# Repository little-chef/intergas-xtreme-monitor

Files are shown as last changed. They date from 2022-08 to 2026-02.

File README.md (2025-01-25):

# Home-Assistant Intergas Central Heating monitor/controller

This project provides the necessary tools and scripts to monitor/control a Intergas
central heating system via the IDS diagnosis interface.

It connects an ESP32 NodeMCU board through optocouplers to the burner control
board of the Intergas Xtreme. From there detailed statistics are published to
Home Assistant for accurate monitoring/controlling of the device.

This project has only been qualified with a Intergas Xtreme 36 central heater.

## Features:

This project allows deep monitoring/controlling of all internal metrics/settings of the Intergas Xtreme.
(Screenshots below only show a subset of he possible settings, full list can be found [here](./esphome/intergas-xtreme-monitor.yaml#L83))

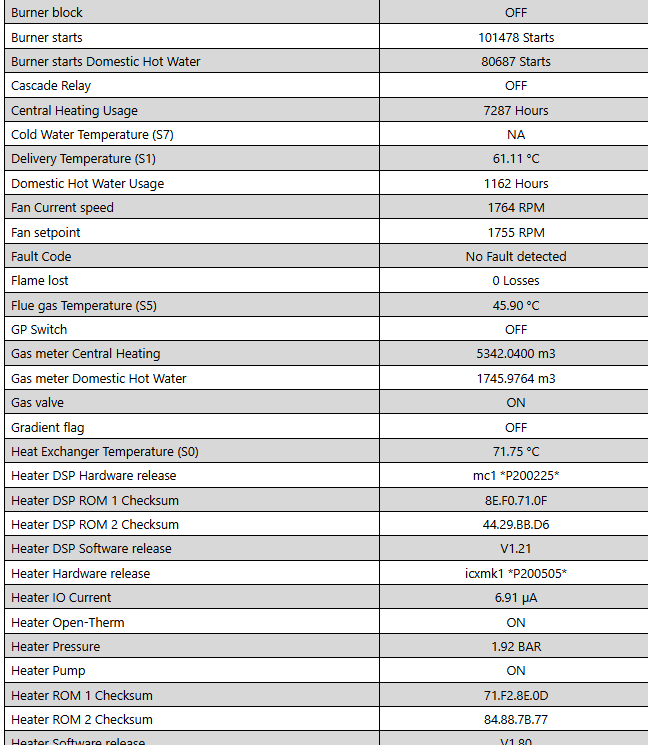
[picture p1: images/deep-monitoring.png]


It also aenables control of all configuration settings of the Intergas Xtreme via Home-Assistant,
including all 'Expert Settings'. This enables keeping track of these settings over time, and easy revert back
to older settings.
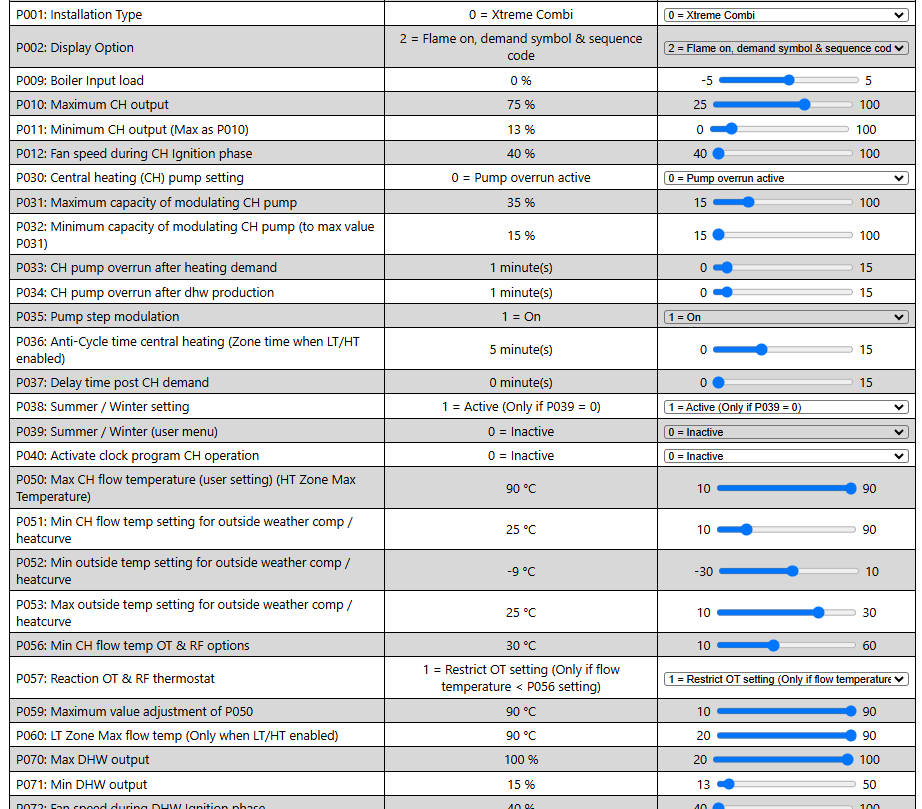
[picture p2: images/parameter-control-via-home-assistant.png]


# Home Assistant
The connection to Home Assistant is done via ESPHome and Wifi.

# Physical connection

Prerequisites for the physical connection:
* Cable required that connect to the X14 connector of the burner control board.
  The type of connector is a Molex Mini-Fit, Jr. connector housing with female
  terminals.

  For reference, the connector is:
  * [Molex part number 39-01-2200](https://www.conrad.nl/p/molex-39012040-mini-fit-jr-receptacle-housing-dual-row-4-circuits-ul-94v-2-natural-2448286), and
  * [the terminals are Molex part number 5556](https://www.conrad.nl/p/molex-39000078-100-pcs-mini-fit-female-crimp-terminal-tin-sn-over-copper-cu-plated-brass-16-awg-bag-2448254).

  This is also the same type of connector you can find on old ATX Power Supplies.

* As opto coupler we use the [4N25](https://www.conrad.nl/p/lite-on-optocoupler-fototransistor-4n25-dip-6-transistor-dc-1127375) type.

* As controller we use:
  * a [NodeMCU-32s (ESP32)](https://docs.platformio.org/en/latest/boards/espressif32/nodemcu-32s.html) Development board

# Schematics design

Schematics of the IDS adapter is designed with KiCad.
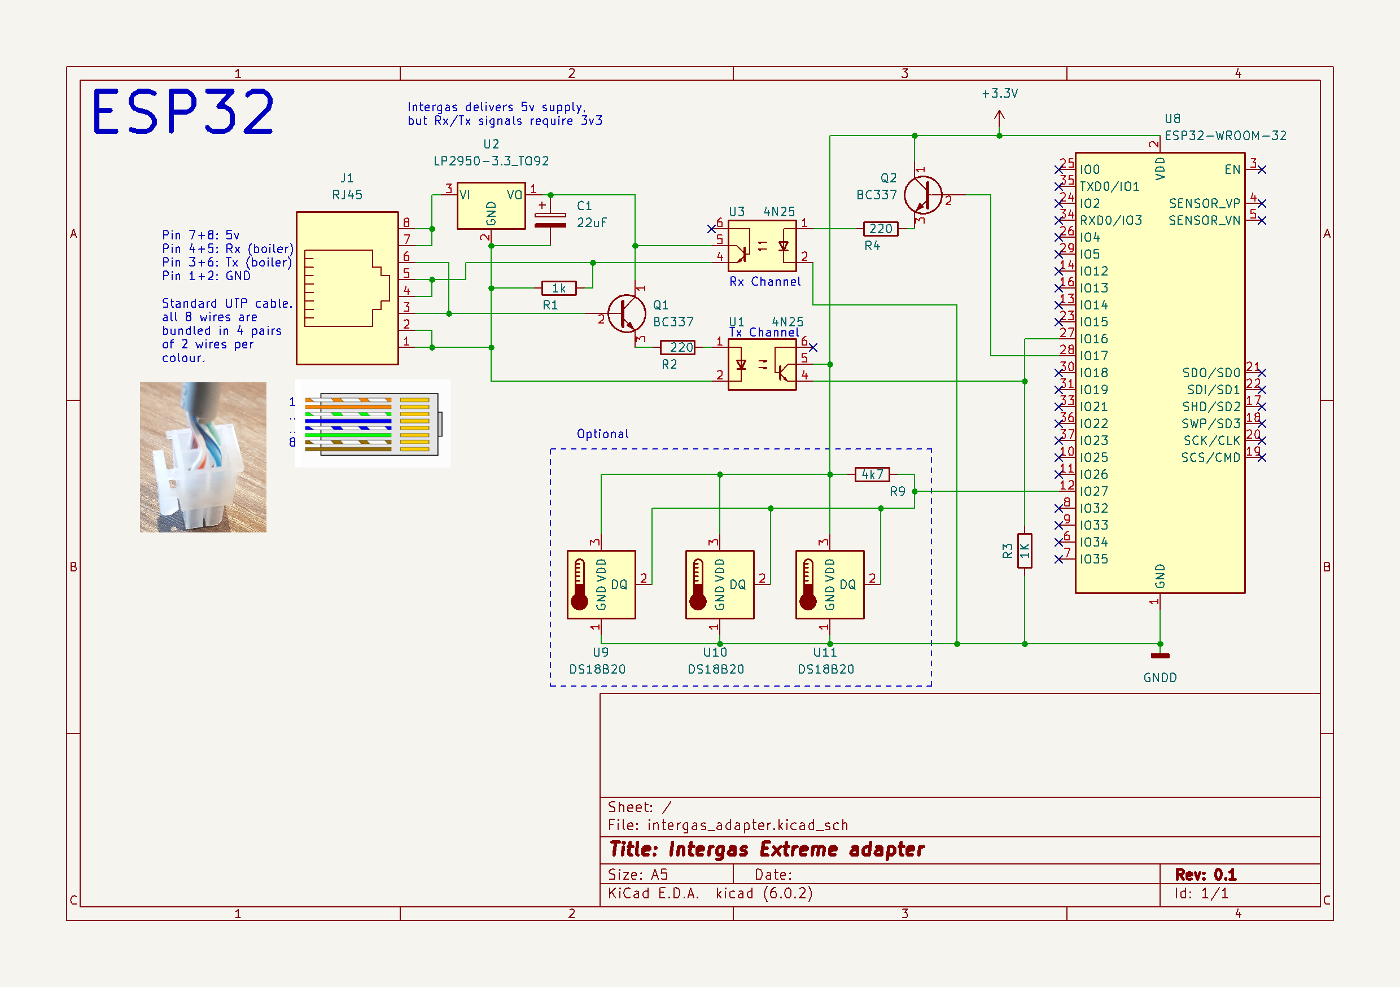
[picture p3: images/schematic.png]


# Cabling
The intergas heater provides a 5V power supply via the X14 connector, but the datalines require 3,3V.

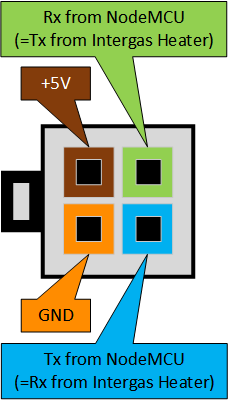
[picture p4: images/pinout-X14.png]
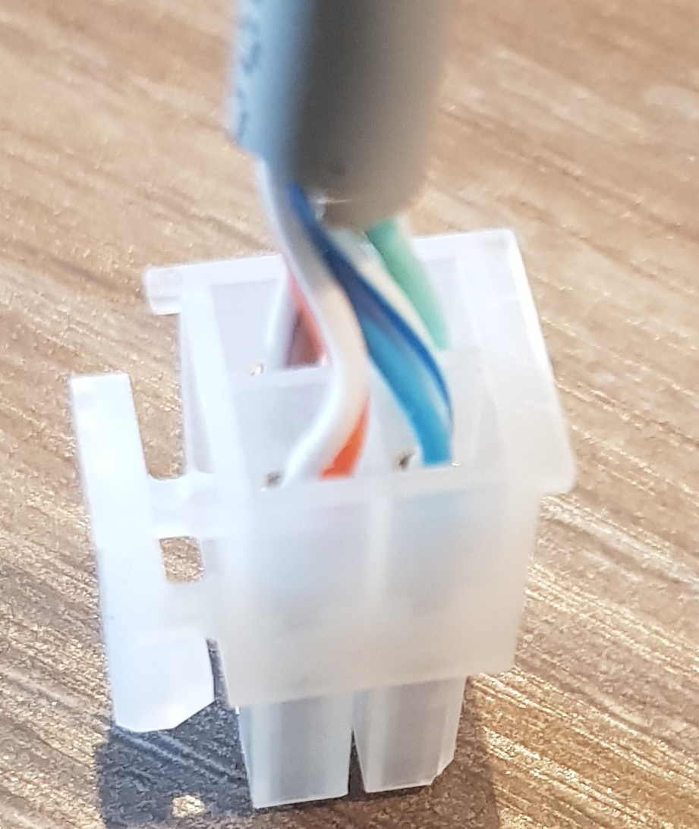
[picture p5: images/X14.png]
|||

# SW Installation

Here are the installation steps for the software in ESPHome:
* First install the ESPHome toolset on Home Assistant via the Addon Store.
* Open an SSH session to your Home-Assistant instance, then
  ```
  $ cd config
  $ git clone https://github.com/little-chef/intergas-xtreme-monitor.git esphome/intergas-xtreme
  $ echo '<<: !include intergas-xtreme/esphome/intergas-xtreme-monitor.yaml' > esphome/intergas-xtreme-monitor.yaml
  ```
  Next create the config/secrets.yaml file and add the following lines:
  ```
  esphome_hassio_api_encryption_key: my-32-byte-base64-encryption-key
  esphome_hassio_ota_pw: my-very-secure-ota-pw
  esphome_wifi_network_ssid: my-wifi-access-point
  esphome_wifi_network_password: my-wifi-password
  esphome_wifi_ap_fallback_password: my-fallback-password
  ```
  The api_encryption key is explained here: https://esphome.io/components/api.html?highlight=randomly%20generated

* Go to the ESPHome dashboard on Home Assistant, the new device should be visible. From
  here you can compile the firmware for the NodeMCU, and install it to NodeMCU device.
* Once the device is running, a new notification will pop up to register the device to your
  Home Assistant instance. Complete that procedure.
* After everything is successful, the metrics will become visible on the Home Assistant Dashboard.

# External references:

The code and content have been inspired by these public sources:
* https://github.com/keesma/Intergas-Central-Heating-Monitor-Homie
* https://www.circuitsonline.net/forum/view/80667/last
* https://github.com/rickvanderzwet/IntergasBoilerReader
* https://github.com/Meewis/ESP8266_MQTT_INTERGAS
* https://gathering.tweakers.net/forum/list_messages/2056344
* https://theintergasshop.co.uk/content/181-intergas-boiler-manuals -> IDS X Range Software

# Final Note:

Note that nothing in this project is supported by Intergas, neither is
there any guarantee that the provided materials will work in your environment.
Be aware that making mistakes in setting up the project may damage your heater
or void your warranty. Use of anything provided of this project is at your own
risk.

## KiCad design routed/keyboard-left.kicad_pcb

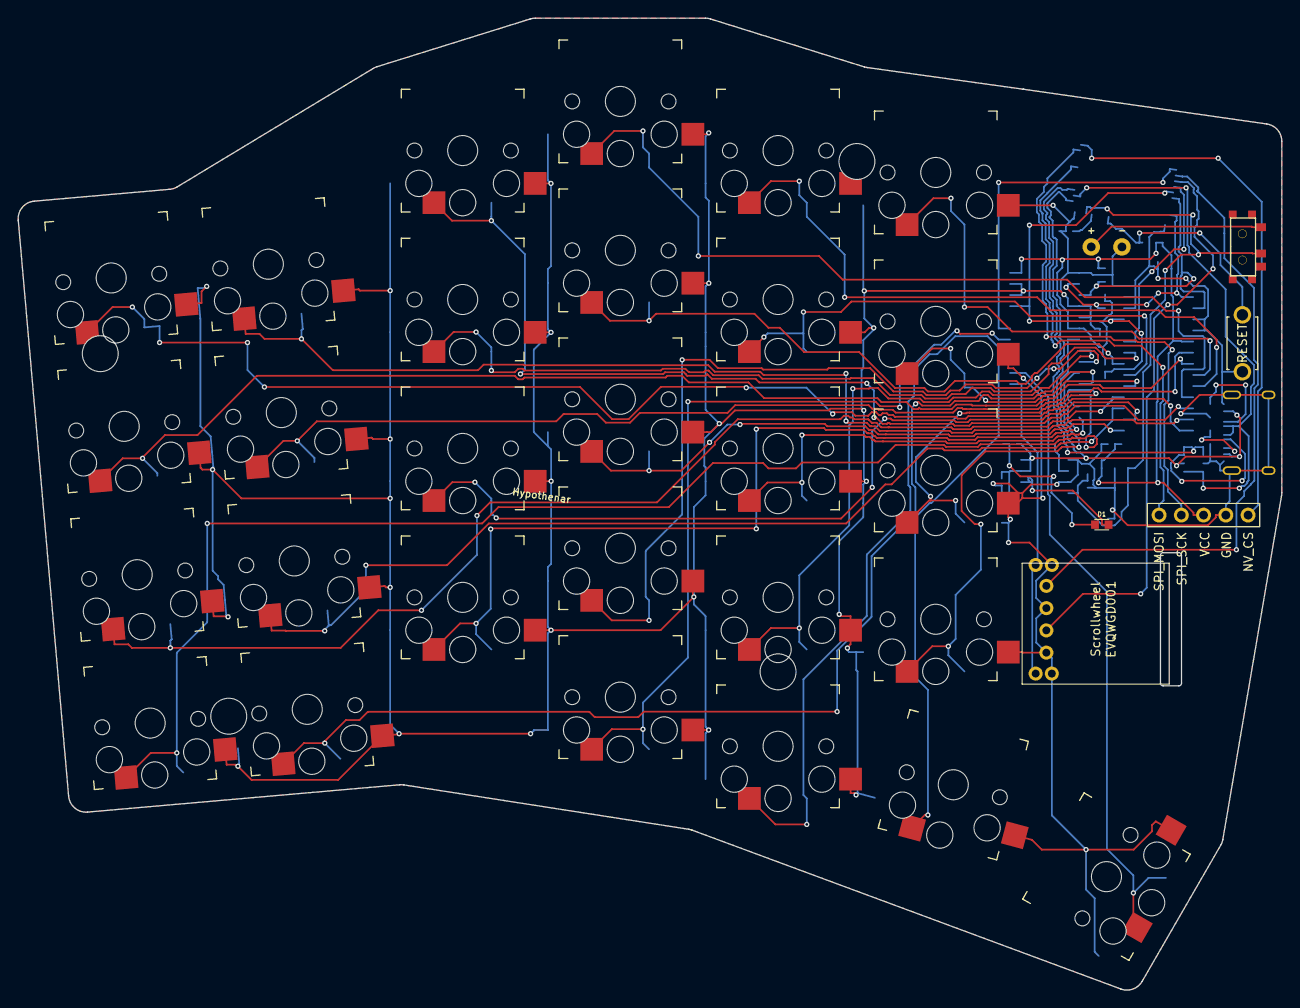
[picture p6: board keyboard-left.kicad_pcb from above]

Board: 2 copper layers, 144.2 x 110.9 mm, 60 parts (0 on the bottom side), 50 nets.

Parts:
19.051: ms88sf3
19.052, 19.053: MCP23017; MCP23017_SOIC-28W
19.054: USB_C_Receptacle_HRO_TYPE-C-31-M-12
19.055: USBLC6-2SC6; USBLC6-2SC6_SOT-23-6
19.056: TP4056; TP4056_SOP-8
19.057: XC6206P332MR; XC6206_SOT-89-3
BT1: BATTERY; battery_pads
DISP1: display_nice_view
P1: C1; passive_0603
P2: C2; passive_0603
P3: C3; passive_0603
P4: C4; passive_0603
P5: C5; passive_0603
P6: C6; passive_0603
P7: C7; passive_0603
P8: C8; passive_0603
P9: R1; passive_0603
P10: R2; passive_0603
P11: R3; passive_0603
P12: R4; passive_0603
P13: R5; passive_0603
P14: R6; passive_0603
P15: R7; passive_0603
P16: R8; passive_0603
P17: D1; passive_0603
S1, S2, S3, S4, S5, S6, S7, S8, S9, S10, S11, S12, S13, S14, S15, S16, S17, S18, S19, S20, S21, S22, S23, S24, S25, S26, S27, S28: PG1350
T1: SPDT_C128955
_1: ResetSW
_2, _3, _4, _5: Hole

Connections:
CHARGE_ACTIVE: 19.056.6, P17.2
CHG_LED: P16.2, P17.1
GND: 19.051.1, 19.051.18, 19.051.34, 19.052.10, 19.052.11, 19.052.14, 19.052.15, 19.052.16, 19.052.17, 19.053.10, 19.053.11, 19.053.14, 19.053.16, 19.053.17, 19.054.A1, 19.054.A12, 19.054.B1, 19.054.B12, 19.054.SH, 19.055.2, 19.056.1, 19.056.3, 19.057.2, BT1.2, DISP1.4, P1.2, P2.2, P3.2, P4.2, P5.2, P6.2, P7.2, P8.2, P11.2, P12.2, P13.2, S1.2, S2.2, S3.2, S4.2, S5.2, S6.2, S7.2, S8.2, S9.2, S10.2, S11.2, S12.2, S13.2, S14.2, S15.2, S16.2, S17.2, S18.2, S19.2, S20.2, S21.2, S22.2, S23.2, S24.2, S25.2, S26.2, S27.2, S28.2, _1.2
I2C_RESET: 19.051.13, 19.052.18, 19.053.18, P14.2
I2C_SCL: 19.051.14, 19.052.12, 19.053.12, P9.2
I2C_SDA: 19.051.17, 19.052.13, 19.053.13, P10.2
MCP_A_INT: 19.051.12, 19.052.20
MCP_B_INT: 19.051.9, 19.053.20
NV_CS: 19.051.45, DISP1.5
PROG: 19.056.2, P13.1
RESET: 19.051.28, P15.2, _1.1
SPI_MOSI: 19.051.41, DISP1.1
SPI_SCK: 19.051.44, DISP1.2
USB_CC1: 19.054.A5, P11.1
USB_CC2: 19.054.B5, P12.1
USB_DM: 19.051.36, 19.054.A7, 19.054.B7, 19.055.3, 19.055.4
USB_DP: 19.051.37, 19.054.A6, 19.054.B6, 19.055.1, 19.055.6
VBAT: 19.051.32, 19.056.4, 19.057.1, P3.1, P4.1, T1.2
VBAT_SW: BT1.1, T1.1
VBUS: 19.051.35, 19.054.A4, 19.054.A9, 19.054.B4, 19.054.B9, 19.055.5, 19.056.7, 19.056.8, P1.1, P2.1, P16.1
VCC: 19.052.9, 19.053.9, 19.053.15, 19.057.3, DISP1.3, P5.1, P7.1, P8.1, P9.1, P10.1, P14.1, P15.1
VDD_MCU: 19.051.31, P6.1
sw_matrix_index_bottom: 19.053.7, S19.1
sw_matrix_index_home: 19.053.1, S20.1
sw_matrix_index_mod: 19.053.22, S18.1
sw_matrix_index_num: 19.052.5, S22.1
sw_matrix_index_top: 19.052.23, S21.1
sw_matrix_inner_bottom: 19.053.8, S23.1
sw_matrix_inner_home: 19.053.2, S24.1
sw_matrix_inner_num: 19.052.6, S26.1
sw_matrix_inner_top: 19.052.24, S25.1
sw_matrix_middle_bottom: 19.053.6, S14.1
sw_matrix_middle_home: 19.052.28, S15.1
sw_matrix_middle_mod: 19.053.21, S13.1
sw_matrix_middle_num: 19.052.4, S17.1
sw_matrix_middle_top: 19.052.22, S16.1
sw_matrix_outer_bottom: 19.053.3, S1.1
sw_matrix_outer_home: 19.052.25, S2.1
sw_matrix_outer_num: 19.052.1, S4.1
sw_matrix_outer_top: 19.052.7, S3.1
sw_matrix_pinky_bottom: 19.053.4, S5.1
sw_matrix_pinky_home: 19.052.26, S6.1
sw_matrix_pinky_num: 19.052.2, S8.1
sw_matrix_pinky_top: 19.052.8, S7.1
sw_matrix_ring_bottom: 19.053.5, S9.1
sw_matrix_ring_home: 19.052.27, S10.1
sw_matrix_ring_num: 19.052.3, S12.1
sw_matrix_ring_top: 19.052.21, S11.1
sw_thumbs_layer_cluster: 19.053.23, S27.1
sw_thumbs_space_cluster: 19.053.24, S28.1

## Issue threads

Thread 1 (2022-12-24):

communication

So871, 2022-12-24:
Hey kerel,
ik probeer jouw code met esphome en een 8266, echter krijg ik er geen data uit.
heb een hre , en gebruik de rx en tx pinnen,

hardware werkt wel met de code van meewis met mqtt en node red,.
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

little-chef, 2022-12-24:
Hoi,
Deze code is gemaakt voor de Xtreme serie en niet de HRE. Het protocol met de ketel is anders, de Xtreme heeft allerlei CRC checks die de HRE niet heeft en de data zit op andere plaatsen in de berichten. Ik verwacht dat dit alleen verkeerde resultaten geeft, maar wel degelijk iets van data.

Bij de 8266 wordt er een andere UART gebruikt (zie documentatie), met pin swapping om te voorkomen dat de bootlogging van esphome naar de ketel gestuurd wordt die mogelijk enkele random instellingen van de ketel zou kunnen overschrijven.
Waarschijnlijk gebruik je de verkeerde pinnen voor rx en tx. In de documentatie bij de code staat precies hoe je het aan moet sluiten.

Daarbij gebruik ik de 8266 niet meer omdat deze tegen memory fragmentatie issues aanloopt waardoor wifi traag en instabiel wordt zodat over-the-air updates niet meer werken. Alleen de esp32 is nog ondersteunt.

So871, 2022-12-28:
Dank voor de reactie ,

Ik heb hier zelf helaas niet genoeg kaas van gegeten om de code aan te passen.

Ik gebruik gpio 1 en 3 , een vriend van mij heeft het schema van keesma vertaald naar een custom pcb.

Als ik de data onderschep met een ttl stick met jou code zie ik wel degelijk S?/r binnenkomen , dus verzenden gaat goed.
Nu nog zien uit te vogelen waarom de ketel geen antwoord geeft.

little-chef, 2022-12-28:
De mainline code is alléén voor de ESP32. Werkt niet met de ESP8266, en als het werkt is wifi niet stabiel. Ook is de code voor de Xtreme, en niet de HRE.
In de historie zie je een commit die de support voor ESP8266 verwijderd, de laatste commit daar voor zou moeten werken mits je GPIO13 en GPIO15 gebruikt. Als je GPIO 1 en 3 wilt gebruiken moet je die code aanpassen, en wordt het nog leuk als je zo af en toe spontaan wat instellingen ziet veranderen in de ketel.
Het schema van keesma komt niet overeen met het schema wat in dit project staat, de code is alleen geschreven voor en getest met het schema in dit project.

So871, 2022-12-29:
Duidelijk,

Correctie : niet het schema van Keesma maar van Meewis gebruikt.
Maar ook die is 3.3V
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

Ik ga jouw schema nabouwen en kijken of ik er dan leven uit krijg.
Met jouw code als basis moet ik toch een heel eind in de buurt zitten.

So871, 2023-01-07:
hey kerel,
ik heb met de esp32 weinig succes met de hre, ik zie een response maar dat is een bijzonder vreemd response
met in laatste commit naar esp8266 en de aangepaste punten krijg ik er netjes antwoord van.
maar ben zelf geen ster in c++ dus het is mij een raadsel waarom ik nu geen normaal response krijg,
 jij misschien een idee?

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

little-chef, 2023-01-07:
In een goede situatie krijg je precies 32/33 bytes binnen, dit lijkt random data, lijkt alsof de verkeerde pin gebruikt worden voor de rx lijn.

tim427, 2024-01-29:
> hey kerel, ik heb met de esp32 weinig succes met de hre, ik zie een response maar dat is een bijzonder vreemd response met in laatste commit naar esp8266 en de aangepaste punten krijg ik er netjes antwoord van. weliswaar met de OTA problemen waar je voor waarschuwde. maar ben zelf geen ster in c++ dus het is mij een raadsel waarom ik nu geen normaal response krijg, jij misschien een idee?
>
> 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

@So871 heb je de aangepaste versie ergens online staan? En https://github.com/little-chef/intergas-xtreme-monitor/issues/4#issuecomment-1839169443 heb je het over jouw versie van PCB ergens gedeeld te hebben; ik ben zeer geïnteresseerd ;)

Closed 2022-12-26.

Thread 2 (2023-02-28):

going offline in the morning

So871, 2023-02-28:
hello,  ( goede morgen)

i'm having some issues with my setup on a HRE, i adopted your code and edited the datapoints, so far so good,
but for some reason the node keeps going offline, especially in the morning ( 06:00-07:00) when i try to log it serially , at the moment is goes offline the output starts giving gibberish ,

is there anything in the code that can explain a timed issue ?

little-chef, 2023-03-04:
Hi,
In my case the instance is not running for 280 hours 53 minutes and 35 seconds, that is is since the last update op ESPHome I did. in my case the only reason to reboot the device is only because of updates, apart from that it is rock solid. So, no: I cannot explain it from code perspective.
If hangup is time specific during the night you need to wonder if the wifi access point is not rebooting at that time, and the wifi connection just gets recovered poorly.

renini, 2023-03-21:
First of all, very cool project, thanks for all the hard work. I have something similar, with an Xtreme 36. Although i haven't pinpointed it to the morning yet, (only have it connected for 3 days), but had to power cycle 3 times also. Will do some more digging and see if I can get console output. Wifi signal shouldn't be the issue in my case at least, feels more like a memory leak thing as it seems to take some time before being "unavailable".

little-chef, 2023-03-23:
If it would be memory leaks, it would not explain why it runs for many weeks in my case, and 3 days somewhere else. I do have a bunch of onewire sensors connected to it. If there are no one-wire sensors then perhaps it is better to disable it altogether in the yaml file.

renini, 2023-03-26:
I agree, i had disabled the onewire code, as i suspected this might be causing it too, but it still happened. For example last night, with a ping/icmp monitor i noticed that the esp32 missed 3 pings around 03:34 last night; at 04:44 it was up again, only to go down again at 05:25, which it currently still is (unfortunately i have no logging), I will investigate some more to see if i can correlate more information and get logging.

What model Xtreme are you having yourself?

Closed 2023-03-04.

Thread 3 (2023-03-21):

Requesting conversion failed for dallas.sensor:112

renini, 2023-03-21:
Hi, many thanks for all the work around this project, it gives me many insights in data from my **Xtreme 36**.

I have a question or issue though and I'm not really sure where to start troubleshooting this and if it is a real issue.

Getting the following error:
`[E][dallas.sensor:112]: Requesting conversion failed`

Every minute, I seem to be getting most the sensor data though, and fwiw I'm on esphome v2023.3.0 and using a ESP-WROOM-32.

More output:
```
[08:13:42][D][Intergas Xtreme:273]: Send command S?\r
[08:13:43][D][sensor:127]: 'Water meter': Sending state 98.64420 m3 with 4 decimals of accuracy
[08:13:43][E][dallas.sensor:112]: Requesting conversion failed
[08:13:43][I][Intergas Xtreme:397]: Response S?\r Data: BB.11.92.0E.14.EC.8B.0E.14.EC.41.0C.79.00.00.00.34.08.14.EC.81.3E.00.00.7E.00.90.40.20.04.00.FF.89 (33)
[08:13:43][D][text_sensor:067]: 'Heater ROM 2 Checksum': Sending state '94.88.6B.77'
[08:13:43][I][Intergas Xtreme:264]: Monitor Idle
[08:13:44][D][Intergas Xtreme:273]: Send command S2\r
[08:13:44][I][Intergas Xtreme:397]: Response S2\r Data: 00.00.00.0D.00.00.6C.07.8D.07.00.00.FF.7F.FF.7F.FF.7F.0F.39.FF.00.FF.FF.FF.82.57.57.61.F8.9C.D3.0E (33)
[08:13:45][E][dallas.sensor:112]: Requesting conversion failed
[08:13:45][I][Intergas Xtreme:264]: Monitor Idle
[08:13:45][I][Intergas Xtreme:264]: Monitor Idle
[08:13:46][D][sensor:127]: 'Ignition failed': Sending state 17.00000 Failures with 0 decimals of accuracy
[08:13:46][D][Intergas Xtreme:273]: Send command D2\r
[08:13:46][I][Intergas Xtreme:397]: Response D2\r Data: 00.00.00.00.00.00.00.00.00.00.00.00.00.00.50.2D.00.00.1B.3A.B3.B0.2C.E1.B0.11.C6.11.00.00.00.00.E4 (33)
[08:13:47][E][dallas.sensor:112]: Requesting conversion failed
[08:13:47][I][Intergas Xtreme:264]: Monitor Idle
```

Any ideas what this could be?

renini, 2023-03-21:
Ow whoops, ignore this. I don't have a DS18B20 sensor at all.

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

Closed 2023-03-21.

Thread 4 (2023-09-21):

PCB Design

thoutenbos, 2023-09-21:
Love this project! Cannot wait to hook it up to my new Xtreme 30

Do you happen to have a PCB design already?

little-chef, 2023-09-23:
Hi,
No, not yet something shareable.

So871, 2023-12-04:
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

Hey sorry for the very long time off, some health issues and a mystic thing called time ..lol

I'll share the Gerber files and schematic for the PCB tomorrow

Closed 2023-09-23.

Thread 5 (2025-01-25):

Werkt deze oplossing nog goed voor de Intergas Xtreme? yaml code lijkt iets gedateerd.

rbak69, 2025-01-25:
I realiseer mij net dat ik dit bericht gewoon in het Nederlands kan schrijven vandaar de edit;-)

Ik heb een Intergas Xtreme en heb de standaard Intergas integratie in Home Assistant geprobeerd. Helaas is de verbinding tussen de gateway en de ketel niet erg stabiel. Daarnaast krijg ik via deze integratie maar beperkte informatie. De informatie die ik eigenlijk zou willen hebben zit daar niet bij.

Uw oplossing lijkt mij wel al de informatie te bieden die ik zou willen hebben. Ik zie alleen dat de yaml code wat gedateerd is. Ik denk dat er slechts kleine aanpassingen nodig zijn om hem weer aan te passen aan de laatste ESPhome verie.

Voordat ik de noodzakelijke hardware aan ga schaffen zou ik graag willen weten of uw oplossing nog steeds zonder problemen werkt met the Intergas Xtreme. Het is immers al een tijd geleden dat de informatie en code ge-update is.

little-chef, 2025-01-25:
Ik had nog een paar commits in mijn backlog staan om te pushen. Dus bij deze is die weer up-to-date.
Bij mij draait deze inmiddels alweer een paar jaar, geen issue mee, dus ja: hij is erg stabiel, mits een ESP32 gebruikt wordt.

rbak69, 2025-01-25:
@little-chef bedankt voor de snelle reactie. Ik ga er ook mee aan de slag want deze oplossing geeft mij volgens mij ook de temperatuur van het retour water in de CV. De intergas gateway is ronduit slecht qua stabiliteit.

Heeft u destijds ook de ketel uitgelezen met IDS (X) software? Zoja heeft u toen rechstreeks een FTDI USB adapter aan de ketel gekoppeld op X14? Gezien uw waarschuwing mbt de oprocoplers ben ik een beetje huiverig om deze op de katel aan te sluiten. Maar zolang de laptop on de accu aangesloten is zou dit volgens mij geen probleem moeten zijn.

little-chef, 2025-01-25:
De Xtreme heeft zelf geen retour temperatuur sensor, dus die kun je ook niet uitlezen...
Ik heb dit opgelost met een onewire sensor die ik met tiewraps tegen de leiding geklemd heb, met stukje buisisolatie er extra omheen: https://www.adafruit.com/product/381
Zo meet ik allerlei waardes, waaronder koud water temperatuur, warm water, zonneboiler, warmtepomp etc.etc.

De link naar de IDSX software staat in het project. Voor experimenteren kun je inderdaad een 3V3 FTDI kabel gebruiken, niet de 5V variant. En die aansluiten aan de ketel, alleen de rx, tx en gnd, geen voeding aansluiten. De originele intergas kabel is ook gewoon een ftdi kabel...

Het is niet bekend in hoeverre de VCC van de ketel is te belasten, om geen risico te lopen heb ik de schakeling gebouwd met optocouplers, daarmee is alles wat je eraan maakt galvanisch gescheiden van de ketel, en wordt die besturing niet verder belast.

little-chef, 2025-01-25:
Maar je hebt geen ketel nodig om iets met de IDSX sw te doen, je kunt ook met 2 USB seriele poorten een loopback maken en daarmee met een Python script of zoiets experimenteren met de data die uitgestuurd en ontvangen wordt

rbak69, 2025-01-25:
Ik had in eerste instantie naar de IDS (X) software gekeken en daar staat wel een sensor voor de “T. retour” in het overzicht vandaar dat ik er van uit was gegaan dat er toch een sensor in zou zitten. Ik had ook naar het kabeltje gekeken en dat leek mij inderdaad een standaard USB FTDI adapter te zijn en zoo'n kabeltje kan je voor een paar euro zelf maken ;-) Puur om op die manier ook de ketel even uit te kunnen lezen.

Ik had in het schema inderdaad de optie voor de DS18B20 (dallas) sensoren gezien. Daar zal ik er ook gelijk een paar van bestellen. Waarschijnlijk 4 om de aanvoer en de retourtemperatuur van de CV op de buis te meten en ook de temperatuur van het koude en warme water. Ondanks dat een deel van de informatie ook uit de ketel te halen is. Gewoon omdat het kan ;-)

In de code zie ik zo snel geen voorbeeld staan onder “sensor” voor de verdere definitie van de DS18B20 sensoren. Heeft u daar ook een voorbeeld van? Ik neem aan dat deze sensoren met een uniek ID werken, staan deze op de sensor zelf als je deze koopt?

Ik had zelf het volgende gevonden als mogelijk voorbeeld:

```
one_wire:
  - platform: gpio
    pin: 5
    id: dallas5

sensor:
  - platform: dallas_temp
    one_wire_id: dallas5
    address: 0xblablabla
    name: "Sensor 1"
    accuracy_decimals: 1
    update_interval: 5s
```

Ik heb aan uw code overigens nog de lijn “safe_mode:” toegevoegd. Misschien niet noodzakelijk als de code al een aantal jaar stabiel loopt maar kan ook geen kwaad denk ik.

Is er wellicht een forum waar ik deze conversatie verder kan voeren? Wellicht is het niet helemaal de juist manier om dat in een “issue” te bespreken.

little-chef, 2025-01-26:
Ik heb een voorbeeld commit toegevoegd voor de one-wire sensors. De regels zijn wel disabled, zodat de code ook werkt als je geen sensors hebt. Die sensors zijn voor iedereen anders.

De one-wire sensors kun je gewoon aansluiten, bij de opstart van de SW staan in het begin van de boot logging alle one-wire sensor IDs die er gevonden zijn. Daarna vul je die IDs in in de YAML file om de mapping compleet te maken.

De IDSX SW is generiek voor een groot aantal ketels, dus vandaar dat die wel de sensor in de metrics heeft staan, alleen die meetwaardes zullen altijd leeg zijn voor de Xtreme.
Ik heb geen forum o.i.d.

little-chef, 2025-01-26:
Safe mode is by-default-enabled wanneer ota gebruikt wordt, hoeft dus niet expliciet toegevoegd te worden, je kunt hem wel disablen als je hem niet wilt

rbak69, 2025-01-26:
Bedankt voor alle antwoorden! Ik ga een lijstje maken met onderdelen die ik moet bestellen en een setup maken op een development board. Dan nog even kijken hoe ik er een definiteve versie van ga maken. Alles op een simpel printje (de optocouplers en de aansluitingen voor meerdere temperatuursensoren) zou ideaal zijn maar aangezien het maar om 1 printje gaat wordt dat denk ik te kostbaar. Maar leuk project!

Overigens de screenshots die u toegevoegd heeft zijn die vanuit Hiome Assistant? Die zien er namelijk mooi en overzichtelijk uit.

little-chef, 2025-01-26:
Bij mij draait het ook nog steeds gesoldeerd op een experimenteerbord.
Nooit de moeite genomen er een pcb van te maken

Op zo 26 jan 2025 13:01 schreef René Bak ***@***.***>:

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

little-chef, 2025-01-26:
Screenshots zijn van de webviewer van esphome van het device, maar het is
dezelfde info als je in home assistant ziet.

Op zo 26 jan 2025 13:01 schreef René Bak ***@***.***>:

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

rbak69, 2025-01-26:
Ah ja ik zet de webserver in mij ESP devices eigenlijk standaard uit want daar kijk ik normaal nooit naar ;-)

rbak69, 2025-02-17:
@little-chef ik wacht op dit moment nog op mijn connector om de schakeling aan de ketel te kunnen koppelen op connector X14. Ik heb een AC/DC powered ESP32-WROOM-32E development board gekocht met 1 relas. De code draait prima voor zoever ik dat zonder aangesloten ketel verder kan controleren.

Maar bij deze nog een vraag met betrekking tot UART2. In jou YAML file staat het volgende om de pinnen voor UART2 te definieren (de standaard gpio pinnen voor UART2 op de ESP32 zijn 16 en 17).

```
uart:
  - id: uart_2
    rx_pin: GPIO16
    tx_pin: GPIO17
    baud_rate: 9600

```
Maar ik zie ook dat op mijn Development board de UART2 RX pin (gpio16) ook gebruikt wordt voor het relais. Dus ik zou eventueel de gpio pinnen voor UART2 aan moeten passen of het relais verwijderen (maar bij voorkeur laat ik deze zitten). IK vermoed dat alks ik de TX van de keten op de RX van mijn development board aansluit de relais gaat lopen klapperen door de data op deze pin.
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
rbak69, 2025-02-17:
OK ik kon niet wachten tot morgen. Heb net de code even iets aangepast en door de gesuggereerde aanpassing in de header file en gpio pin 15 te gebruiken voor UART2 in plaats van gpio 16 kan ik het relais gewoon bedienen. Dus de oude regel code in de header file

`Serial2.begin(9600);
`

maakt inderdaad standaard gebruik van gpio pinnen 16 en 17 en overschrijft dus de toewijzing van de uart in de YAML file als je deze niet expliciet aanpast in de header file.

Nu nog even wachten op de molex connector voordat het testen kan beginnen. Als alles goed functioneert (en daar ga ik wel van uit) ga ik misschien wel een printplaatje maken alleen voor de optocouplers en de 1-Wire sensoren. Dan kan ik deze gebruiken in combinatie met verschillende processoren. Misschien ook wel met een extra LP2950 aan de processor kant ook zodat ik aan beide kanten ook met 5 volt kan voeden. Waarschijnlijk met een jumper zodat ik alsnog kan kiezen tussen 5 volt of 3.3 volt.

rbak69, 2025-02-18:
@little-chef super! Nu is de header file universeel te gebruiken en hoef je de eventuele aanpassingen alleen in de YAML file te doen! Ik heb zelf overigens ook de GPIO pin nummers boven in de TAML file gedefinieerd dan staat dat allemaal mooi op één plek.

```
# substitutions: https://esphome.io/components/substitutions.html
substitutions:
  # Generic
  device_name: "esp32dev-test" # No spaces or underscores allowed for local DNS
  # ESP32 usb-c Development Board (ESP32-WROOM-32D)
  # Onboard LED
  gpio_onboard_led: "GPIO2"            # GPIO2 (connected to buil in led)
  # UART2
  gpio_uart2_rx: "GPIO16"              # GPIO16 = D16 on the esp32dev board
  gpio_uart2_tx: "GPIO17"              # GPIO17 = D17 on the esp32dev board
  # One-Wire
  gpio_one_wire: "GPIO27"              # GPIO27 = D27 on the esp32dev board

```
Heeft het overigens nog zin om de RX buffer size aan te passen onder de uart definitie?

> rx_buffer_size (Optional, int): The size of the buffer used for receiving UART messages. Increase if you use an integration that needs to read big payloads from UART. Defaults to 256.

Ik las volgens mij dat je normaalgesproken niet meer dan 32 bytes verwacht. Standaard is de buffer size 256 dus ik weet niet of dat nog voordeel heeft voor het gebruikte geheugen of dat dit voor de ESP32 nog extra scheelt qua tijd die de processor nodig heeft.

Dit is zoals ik het op dit moment in mijn aangepaste code heb staan:

```
# - We will use UART2 for the communication to the Intergas Xtreme heater.
# - We use optocouplers to decouple from feeding back any voltage from the
#   heater into the GPIO pins on the ESP32, and to galvanic decouple the monitor
#   from the central heating system and to reduce the risk of damaging it when
#   some malfunction happens inside the monitor.
# uart: https://esphome.io/components/uart.html
uart:
  id: "uart_heater"
  # UART2 specific GPIO pin details
  rx_pin: "${gpio_uart2_rx}"
  tx_pin: "${gpio_uart2_tx}"
  baud_rate: 9600
#  rx_buffer_size: 256
  debug:
    direction: BOTH
    dummy_receiver: false
    after:
      delimiter: "\n"
    sequence:
      - lambda: UARTDebug::log_string(direction, bytes);
```

little-chef, 2025-02-18:
Buffer size maakt niks uit zolang het maar groot genoeg is. Default is
prima.
Logging extra is niet nodig, dat doet de code zelf al.
Settings als in het git project zijn prima, is getest.

Op di 18 feb 2025 22:08 schreef René Bak ***@***.***>:

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

rbak69, 2025-02-26:
Ha @little-chefnog even naar aanleiding van jou laatste update. Wanneer ik de uart debug aan zet met behulp van de volgende configuratie in mijn yaml file:
```
uart:
  id: "uart_heater"
  # UART2 specific GPIO pin details
  rx_pin: "${gpio_uart2_rx}"
  tx_pin: "${gpio_uart2_tx}"
  baud_rate: 9600
#  rx_buffer_size: 256
  debug:
    direction: BOTH
    dummy_receiver: false
    after:
      delimiter: "\n"
    sequence:
      - lambda: UARTDebug::log_string(direction, bytes);
```
Dan zie ik in de uart logs bij alle commands die verstuurd worden een extra karakter staan. Zie hieronder een klein stukje van mijn log, de ketel zit nog niet aangesloten vandaar dat er nog geen antwoord ontvangen wordt:

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

Is mijn aanname juist dat dit geheel volgens verwachting is en dat dit de CRC byte is?

little-chef, 2025-02-26:
Klopt, is CRC byte

Op wo 26 feb 2025 13:27 schreef René Bak ***@***.***>:

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

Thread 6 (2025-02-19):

Custom component (C code) support is verwijderd. Code moet aangepast worden naar External component (volledig yaml)

rbak69, 2025-02-19:
Vandaag een nieuwe versie van de ESPHome Buidler geinstalleerd en bij het compileren krijg ik de volgende fout.

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

Het lijk er dus op dat de code aangepast zal moeten worden van een "Custom" component (de header file) naar een "External" component (volledig yaml) voor ESPHome 2025.2.0.

rbak69, 2025-02-19:
Begrijp ik. Ik ben weer terug gegaan naar de vorige ESPhome versie.

little-chef, 2025-02-20:
Hi,

Uploaded a containment of the build failure due to the upgrade to esphome
2025.2.0.

Note that this is just a containment of the issue and a structural solution
is being created. That requires a major overhaul of the codebase and will
take some time. In the meantime, this solution works with 2025.2.0 and
probably also beyond.

Op wo 19 feb 2025 20:18 schreef Remy Böhmer ***@***.***>:

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

rbak69, 2025-02-26:
Ha @little-chef misschien op dit moment wat minder relevant omdat je bezig bent met een volledige rewrite maar wanneer ik de uart debug aan zet met behulp van de volgende configuratie in mijn yaml file:
```
uart:
  id: "uart_boiler"
  # UART2 specific GPIO pin details
  rx_pin: "${gpio_uart2_rx}"
  tx_pin: "${gpio_uart2_tx}"
  baud_rate: 9600
#  rx_buffer_size: 256
  debug:
    direction: BOTH
    dummy_receiver: false
    after:
      delimiter: "\n"
    sequence:
      - lambda: UARTDebug::log_string(direction, bytes);
```
Dan zie ik in de uart logs bij alle commands die verstuurd worden een extra karakter staan. Zie hieronder een klein stukje van mijn log, de ketel zit nog niet aangesloten vandaar dat er nog geen antwoord ontvangen wordt:

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

Is mijn aanname juist dat dit geheel volgens verwachting is en dat dit de CRC byte is?

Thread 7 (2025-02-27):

Is deze code ook geschikt voor de intergas hre variant

mcjackdus, 2025-02-27:
Ik heb de aangepaste versie van deze code van https://github.com/So871 gebruikt voor mijn Intergas Hre ketel.
De code werkt prima maar er zijn wat dingen die volgens mij niet helemaal overeen komen tussen de beide ketel varianten.
Voorbeeld daarvan zijn de foutcode's.
Ik zie ook dat het mogelijk is om parameters te wijzigen.

Het lijkt erop dat de code van So871 niet verder in ontwikkeling is.
In hoever is deze code ook geschikt voor de Intergas HRE variant?

little-chef, 2025-02-27:
De code is alleen geschikt voor de Xtreme. De HRE heeft andere commando's,
ander gedrag bij de CRC checksums, en heeft andere data velden.
In de basis kan de code werken, maar er moeten veel aanpassingen gedaan
worden.

Op do 27 feb 2025 14:15 schreef mcjackdus ***@***.***>:

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

little-chef, 2025-02-27:
Als ik naar die code kijk zie ik een slecht geimplementeerde halve kopie
van dit project. Ik stel voor dat je de eigenaar van dat project om hulp
vraagt. Ik voel me niet geroepen dat te supporten.

1 hint wil ik je nog geven, kijk hoe de IDS software zich gedraagt op de
seriele bus, en pas daar je code op aan.

Op do 27 feb 2025 21:15 schreef mcjackdus ***@***.***>:

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

little-chef, 2025-02-27:
Closed, this is not an issue in this project

Closed 2025-02-27.

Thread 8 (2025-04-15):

IDS adapter

rweijnen, 2025-04-15:
This is really a question and not an issue but since I lack the skills to create the IDS adapter I was wondering if you happen to have one available or could create one? I'm happy to reimburse you for parts and reasonable labour costs.

I have an Kombi Kompakt HRE 36/30 A 60/100 TSK/RGK so as I understand it the protocol differs from yours. But software and reverse engineering I am comfortable with so I'd love to analyze the PC software and adapt your code for it. This would also need a PC cable to connect with the Intergas?

If you can't / don't have time I understand of course and in that case just let me know and close the issue.

little-chef, 2025-04-15:
No, I do not have spare adapters, neither will there be one...
The cable and adapter should be the same for this type of heater though.

Closed 2025-04-15.

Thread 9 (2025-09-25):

Thanks & small donation?

jeffreyveldt, 2025-09-25:
Hi Little-chef,

I’ve been using intergas-xtreme-monitor for quite a while now, and it’s been working great for me. Thank you for making and sharing this project! 🙏

I’d like to buy you a cup of coffee (or beer 🍺) as a small token of appreciation. Do you have a preferred way to receive donations (e.g. PayPal, Ko-fi, GitHub Sponsors)?

Thanks again for your work on this project!

Best,

Jeffrey

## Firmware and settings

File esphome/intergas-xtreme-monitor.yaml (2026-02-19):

substitutions:
  devicename: intergas-xtreme-monitor
  friendly_devicename: Intergas Xtreme monitoring
  device_description: 'Device for monitoring and remotely configure an Intergas Xtreme heating system'

esp32:
  board: nodemcu-32s
  framework:
    type: esp-idf

esp32_improv:
  authorizer: none

# Enable logging
# The ESP32 has 3 UARTs:
# UART0 is used for logging output.
# UART2 is used for communicating to the heater
#
# - We use Tx and Rx from UART2.
# - We use optocouplers to decouple from feeding back any voltage from the
#   heater into the GPIO16+GPIO17 pins, and to galvanic decouple the monitor
#   from the central heating system and to reduce the risk of damaging it when
#   some malfunction happens inside the monitor.
uart:
  - id: uart_boiler
    rx_pin: GPIO16
    tx_pin: GPIO17
    baud_rate: 9600

logger:
  hardware_uart: UART0
  level: DEBUG
  baud_rate : 115200

web_server:
  port: 80

output:
  - platform: ledc
    id: onboard_led
    pin:
      number: GPIO2

# A number of One-Wire sensors can be added to the ESP32.
one_wire:
  - platform: gpio
    pin: GPIO27

esphome:
  name: ${devicename}
  friendly_name: "${friendly_devicename}"
  comment: "${device_description}"
  includes:
    - intergas-xtreme/esphome/IntergasXtremeMonitor.h
    - intergas-xtreme/esphome/IntergasXtremeMonitor.cpp
  build_path: "../config/esphome/build/$devicename"

globals:
  - id: intergas_xtreme_monitor
    type: void *
    restore_value: no
    initial_value: 'nullptr'

script:
  - id: set_param
    parameters:
        param: uint8_t
        value: float
    then:
      - lambda: |-
          auto & obj =
              *static_cast<esphome::intergas_xtreme_monitor_component::IntergasXtremeMonitor*>(
                  id(intergas_xtreme_monitor));
          obj.set_param(param, value);
  - id: set_select_param
    parameters:
        param: uint8_t
        select: select::Select*
        text_value: std::string
    then:
      - lambda: |-
          auto & obj =
              *static_cast<esphome::intergas_xtreme_monitor_component::IntergasXtremeMonitor*>(
                  id(intergas_xtreme_monitor));
          obj.set_select_param(param, select, text_value);

interval:
  - interval: 0.5s
    startup_delay: 10s
    then:
      - lambda: |-
          if (id(intergas_xtreme_monitor)) {
            auto & obj =
                *static_cast<esphome::intergas_xtreme_monitor_component::IntergasXtremeMonitor*>(
                    id(intergas_xtreme_monitor));
            obj.update();
          } else {
            ESP_LOGI("on_boot", "On boot initialize");
            id(intergas_xtreme_monitor) =
              new esphome::intergas_xtreme_monitor_component::IntergasXtremeMonitor(
                // BinarySensor *
                heater_alarm_status,
                heater_burner_block,
                heater_cascade_relay,
                heater_gas_valve,
                heater_gp_switch,
                heater_gradient_flag,
                heater_has_low_water_pressure,
                heater_ionisation_signal,
                heater_open_therm,
                heater_ot_disabled,
                heater_pump_running,
                heater_roomtherm,
                heater_spark,
                heater_tap_switch,

                // Number *
                anti_pendulum_time_heating,
                comfort_keep_temperature,
                comfort_offset,
                control_temperature_boiler_operation,
                delivery_temperature_control_panel,
                dhw_temp_setting,
                heatcurve_maximal_outside_temperature,
                heatcurve_minimal_delivery_temperature,
                heatcurve_minimal_outside_temperature,
                load_adjustment,
                lt_zone_setpoint_max,
                max_heating_power,
                max_setting_p050,
                max_water_heating_power,
                min_heating_delivery_temp_ot_and_rf,
                min_heating_power,
                min_water_heating_power,
                nof_eco_days,
                pump_afterrun_boiler,
                pump_afterrun_central_heating,
                pump_maximum,
                pump_minimum,
                start_rpm_heating,
                start_speed_hot_water,
                wait_time_heating_after_hot_water_delivery,
                wait_time_heating_response,
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

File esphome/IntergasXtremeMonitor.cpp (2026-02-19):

#include "IntergasXtremeMonitor.h"
#include "esphome/core/helpers.h"
#include "esphome/core/log.h"

namespace esphome {
namespace intergas_xtreme_monitor_component {

static constexpr const char* TAG = "Intergas Xtreme";

IntergasXtremeMonitor::IntergasXtremeMonitor(
    binary_sensor::BinarySensor *heater_alarm_status,
    binary_sensor::BinarySensor *heater_burner_block,
    binary_sensor::BinarySensor *heater_cascade_relay,
    binary_sensor::BinarySensor *heater_gas_valve,
    binary_sensor::BinarySensor *heater_gp_switch,
    binary_sensor::BinarySensor *heater_gradient_flag,
    binary_sensor::BinarySensor *heater_has_low_water_pressure,
    binary_sensor::BinarySensor *heater_ionisation_signal,
    binary_sensor::BinarySensor *heater_open_therm,
    binary_sensor::BinarySensor *heater_ot_disabled,
    binary_sensor::BinarySensor *heater_pump_running,
    binary_sensor::BinarySensor *heater_roomtherm,
    binary_sensor::BinarySensor *heater_spark,
    binary_sensor::BinarySensor *heater_tap_switch,

    number::Number *anti_pendulum_time_heating,
    number::Number *comfort_keep_temperature,
    number::Number *comfort_offset,
    number::Number *control_temperature_boiler_operation,
    number::Number *delivery_temperature_control_panel,
    number::Number *dhw_temp_setting,
    number::Number *heatcurve_maximal_outside_temperature,
    number::Number *heatcurve_minimal_delivery_temperature,
    number::Number *heatcurve_minimal_outside_temperature,
    number::Number *load_adjustment,
    number::Number *lt_zone_setpoint_max,
    number::Number *max_heating_power,
    number::Number *max_setting_p050,
    number::Number *max_water_heating_power,
    number::Number *min_heating_delivery_temp_ot_and_rf,
    number::Number *min_heating_power,
    number::Number *min_water_heating_power,
    number::Number *nof_eco_days,
    number::Number *pump_afterrun_boiler,
    number::Number *pump_afterrun_central_heating,
    number::Number *pump_maximum,
    number::Number *pump_minimum,
    number::Number *start_rpm_heating,
    number::Number *start_speed_hot_water,
    number::Number *wait_time_heating_after_hot_water_delivery,
    number::Number *wait_time_heating_response,

    select::Select *activate_clock_program_ch,
    select::Select *dhw_timer,
    select::Select *display_option,
    select::Select *factory_reset,
    select::Select *function_alarm_relay,
    select::Select *function_ext1_temp_input,
    select::Select *function_ext2_temp_input,
    select::Select *function_relay_re1,
    select::Select *function_relay_re2,
    select::Select *function_x10_output,
    select::Select *hot_water_comfort_setting,
    select::Select *installation_type,
    select::Select *legionella_protection,
    select::Select *operation_mode_3_way_valve,
    select::Select *pump_setting,
    select::Select *response_OT_and_RF_thermostat,
    select::Select *step_modulation,
    select::Select *summer_winter_setting,
    select::Select *summer_winter_setting_user,

    sensor::Sensor *burner_start_count,
    sensor::Sensor *burner_starts_dhw_count,
    sensor::Sensor *ch_function_hours,
    sensor::Sensor *dhw_function_hours,
    sensor::Sensor *fanspeed,
    sensor::Sensor *fanspeed_set,
    sensor::Sensor *flame_lost,
    sensor::Sensor *gas_meter_ch,
    sensor::Sensor *gas_meter_dhw,
    sensor::Sensor *heater_io_current,
    sensor::Sensor *ignition_failed,
    sensor::Sensor *line_power_connected_count,
    sensor::Sensor *line_power_connected_hours,
    sensor::Sensor *override_outside_temp,
    sensor::Sensor *pressure,
    sensor::Sensor *pumpspeed,
    sensor::Sensor *pumpspeed_set,
    sensor::Sensor *reset_count,
    sensor::Sensor *tapflow,
    sensor::Sensor *temperature_boiler_to_heater,
    sensor::Sensor *temperature_cold_water,
    sensor::Sensor *temperature_flow,
    sensor::Sensor *temperature_flue_gas,
    sensor::Sensor *temperature_heat_exchanger,
    sensor::Sensor *temperature_hot_water,
    sensor::Sensor *temperature_outside,
    sensor::Sensor *temperature_setpoint,
    sensor::Sensor *water_meter,
    sensor::Sensor *zone1_room_override,
    sensor::Sensor *zone1_room_setpoint,
    sensor::Sensor *zone1_room_temperature,
    sensor::Sensor *zone2_room_override,
    sensor::Sensor *zone2_room_setpoint,
    sensor::Sensor *zone2_room_temperature,

    text_sensor::TextSensor *dsp_hardware_release,
    text_sensor::TextSensor *dsp_rom_test_1_checksum,
    text_sensor::TextSensor *dsp_rom_test_2_checksum,
    text_sensor::TextSensor *dsp_software_release,
    text_sensor::TextSensor *hardware_release,
    text_sensor::TextSensor *heater_dwk,
    text_sensor::TextSensor *heater_fault_code,
    text_sensor::TextSensor *heater_last_fault_code,
    text_sensor::TextSensor *heater_status_code,
    text_sensor::TextSensor *monitor_status,
    text_sensor::TextSensor *production_code,
    text_sensor::TextSensor *rom_test_1_checksum,
    text_sensor::TextSensor *rom_test_2_checksum,
    text_sensor::TextSensor *software_release,

    uart::UARTComponent *uart_boiler,

    output::BinaryOutput *onboard_led

) : heater_alarm_status(heater_alarm_status),
    heater_burner_block(heater_burner_block),
    heater_cascade_relay(heater_cascade_relay),
    heater_gas_valve(heater_gas_valve),
    heater_gp_switch(heater_gp_switch),
    heater_gradient_flag(heater_gradient_flag),
    heater_has_low_water_pressure(heater_has_low_water_pressure),
    heater_ionisation_signal(heater_ionisation_signal),
    heater_open_therm(heater_open_therm),
    heater_ot_disabled(heater_ot_disabled),
    heater_pump_running(heater_pump_running),
    heater_roomtherm(heater_roomtherm),
    heater_spark(heater_spark),
    heater_tap_switch(heater_tap_switch),
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

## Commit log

2022-08-05 rename yaml and header file to match devicename
2022-08-14 Add NodeMCU-ESP32 support
    Next to the NodeMCU-ESP8266 we do now support also a
    NodeMCU-ESP32 board: https://esphome.io/devices/nodemcu_esp32.html
    [intergas_adapter.kicad_sch]
2022-10-23 Drop esp8266 support
    [intergas_adapter.kicad_sch]
2022-10-30 Remove quotes from the device name
    These quotes are not needed
2022-12-26 Export the raw data to the debug logging
    Now with the ESP32 it no longer overloads the system.
2022-12-26 Add support for storing heater parameters
    Temperatures for LT and HT zone are added, and a field for controlling
    the maximum heater power.
    Mark the writeable settings as config items to prevent
    accidental changing them in the dashboard.
    [intergas-xtreme-monitor.yaml]
2022-12-26 Add a couple of configuration parameters for domestic water
    A couple of config items to conigure the domestic water power.
2023-03-18 Change location inside esphome folder
    Recent changes to ESPHome makes it impossible to use symbolic
    links for the yaml files. This causes the builds to fail
    silently. As such we need to move this subproject inside
    the ESPHome folder. Given that the ESPhome only loads yaml
    files from the root of esphome, we need to create a yaml file
    there loading the real one. ESPHome also requires a secrets.yaml
    but does not find it when stored at the original place, hence
    we create a symbolic link to where the file is expected to be.
    [intergas-xtreme-monitor.yaml]
2025-01-25 fix DHW temperature range at P078
    [intergas-xtreme-monitor.yaml]
2025-01-25 fix breaking changes due to ESPHome 2024.06.0
    [intergas-xtreme-monitor.yaml]
2025-01-26 Add example one-wire sensor
2025-02-18 Use UART definition from yaml file
    The C++ code used the Serial2 API for communicating
    with the heating boiler, while there was also a
    definition in the YAML file. That definition is not
    really used and overwritten by the Serial2 usage
    in the C++ code.
    We now use the actual component in the YAML file
    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
2025-08-22 No longer use register_component on ESP-Home 2025.8.0
    App.register_component does not seem to work anymore from a
    on_boot lambda. It results that the polling component is no
    longer calling update(). To solve this we just use a regular
    lambda in an interval component.
    [IntergasXtremeMonitor.cpp, intergas-xtreme-monitor.yaml]
2025-11-30 add esp32_improv
2026-01-25 Replace forward slash by its unicode version
    Forward slash has a special meaning in URL definitions, by replacing it
    with its unicode equivalent this character does not appear anywhere in
    a URL.
    [intergas-xtreme-monitor.yaml]
2026-02-19 Fixes for ESPHome 2026.2.0
    [IntergasXtremeMonitor.cpp, intergas-xtreme-monitor.yaml]
2026-10-11 Add step-by-step assembly guide with perfboard layout (#12)
    Turns the schematic into a perfboard build for beginners: parts, every
    connection by component and pin, a wiring map (SVG), build and test steps,
    the X14 plug orientation, and a read-only ESPHome link test before the
    full firmware. Built and verified on an Intergas Xtreme 30.
    Addresses #11.
